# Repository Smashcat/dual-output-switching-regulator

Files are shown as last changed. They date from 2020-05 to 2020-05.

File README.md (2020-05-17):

# dual-output-switching-regulator
Small board with single 8-26v input and 5V@1.7A + 3.3V@500mA dual output via switching regulator

This board uses the cheap BD93291EFJ switching buck regulator which offers dual output, and is much more efficient than using linear regulators, while also allowing for higher input voltages than typical linear regulators; up to 26V. The board is very small - just 21mm x 30mm, so you can have 20 made at JLCPCB for under $1 :) Pin pitches are all quite large for surface mount, so a stencil isn't necessary to solder this board.

The pin headers are 2.54mm pitch, as the board is designed to be plugged into a breadboard as a convenient dual-rail power supply.

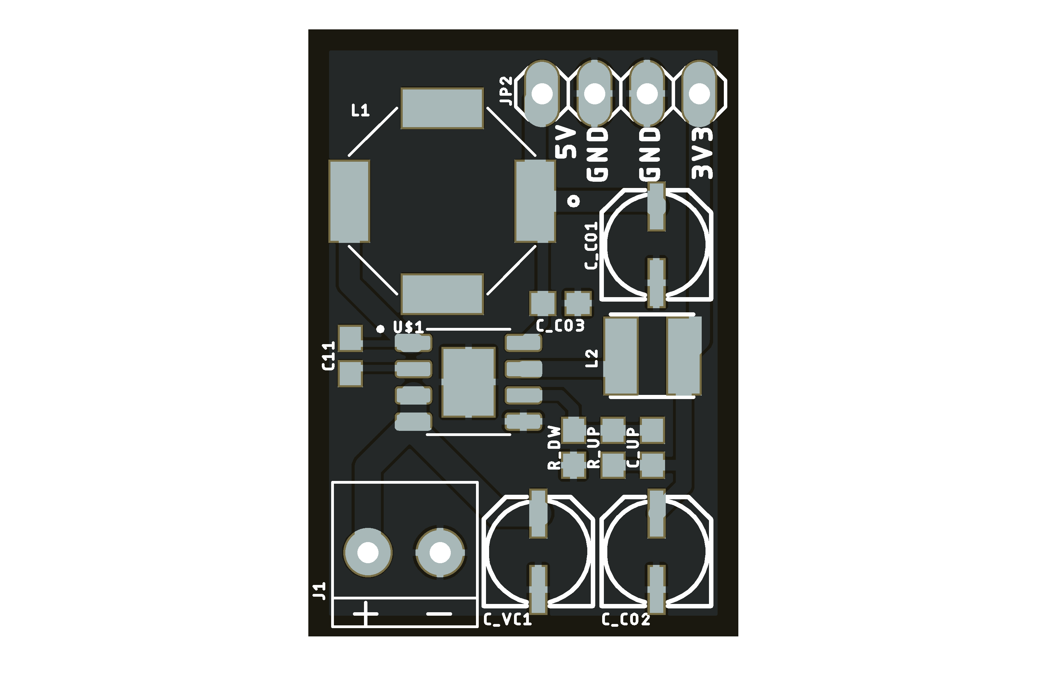
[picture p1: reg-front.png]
Front of PCB


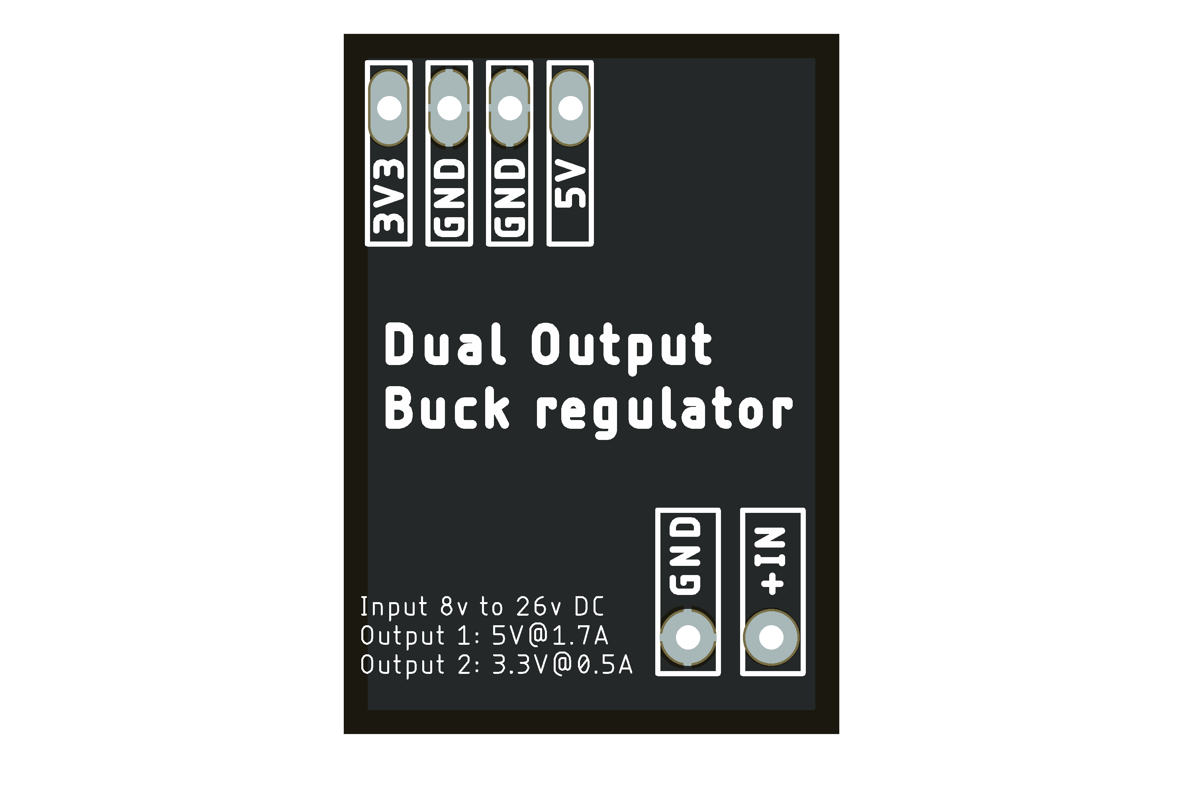
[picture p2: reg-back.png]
Back of PCB


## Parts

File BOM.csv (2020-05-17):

Part | Value | Device | Package | Description
C11 | 0.1uF | 0.1UF-0603-25V-(+80/-20%) | 0603 | 0.1µF ceramic capacitors
C_CO1 | 47uF | 47UF-POLAR-PANASONIC_C-35V-20% | PANASONIC_C | 47µF polarized capacitors
C_CO2 | 47uF | 47UF-POLAR-PANASONIC_C-35V-20% | PANASONIC_C | 47µF polarized capacitors
C_CO3 | 10uF | 10UF-0603-25V-(+80/-20%) | 0603 | 10µF ceramic capacitors
C_UP | 680pF | pF-0603-25V-(+80/-20%) | 0603 | 680pF ceramic capacitors
C_VC1 | 47uF | 22UF-POLAR-PANASONIC_C-35V-20% | PANASONIC_C | 47µF polarized capacitors
J1 | 1X2-3.5MM | 1X2-3.5MM | 1X2-3.5MM | 3.5mm Terminal block
JP2 | 3A | PINHD-1X4 | 1X04 | PIN HEADER
L1 | SRU1063-220Y | SRU1063-220Y | IND_SRU1063-220Y | Ind Power Shielded Wirewound 22uH 30% 100KHz 15Q-Factor Ferrite 3A T/R
L2 | SRN4018-2R2M | SRN4018-2R7M | INDP4040X180N | Inductor Power Semi-Shielded Wirewound 47uH 20% 100KHz Ferrite 600mA 780mOhm DCR 1515 T/R
R_DW | 5K1 | 5K1OHM-0603-1/10W-1% | 0603 | 5.1kΩ resistor
R_UP | 16K | 16KOHM-0603-1/10W-1% | 0603 | 16kΩ resistor
U$1 | BD93291EFJ | BD93291EFJ | SOIC127P600X100-9N

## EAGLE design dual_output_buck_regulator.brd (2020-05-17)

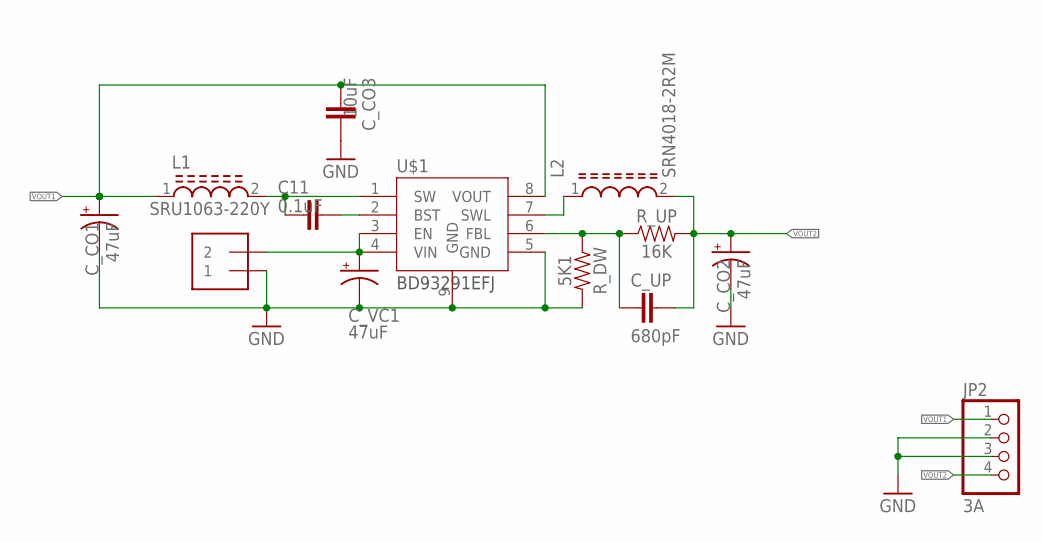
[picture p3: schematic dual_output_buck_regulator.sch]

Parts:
C11: 0.1uF; 0603
C_CO1, C_CO2: 47uF; PANASONIC_C
C_CO3: 10uF; 0603
C_UP: 680pF; 0603
C_VC1: 47uF; PANASONIC_C
J1: 1X2-3.5MM
JP2: 3A; 1X04
L1: SRU1063-220Y; IND_SRU1063-220Y
L2: SRN4018-2R2M; INDP4040X180N
R_DW: 5K1; 0603
R_UP: 16K; 0603
U$1: BD93291EFJ; SOIC127P600X100-9N

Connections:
GND: C_CO1.-, C_CO2.-, C_CO3.1, C_VC1.-, J1.1, JP2.2, JP2.3, R_DW.2, U$1.5 (GND), U$1.9 (GND)
unnamed: C_VC1.+, J1.2, U$1.3 (EN), U$1.4 (VIN)
unnamed: C11.1, U$1.2 (BST)
unnamed: C11.2, L1.2, U$1.1 (SW)
unnamed: C_UP.2, R_DW.1, R_UP.1, U$1.6 (FBL)
unnamed: L2.1, U$1.7 (SWL)
VOUT1: C_CO1.+, C_CO3.2, JP2.1, L1.1, U$1.8 (VOUT)
VOUT2: C_CO2.+, C_UP.1, JP2.4, L2.2, R_UP.2

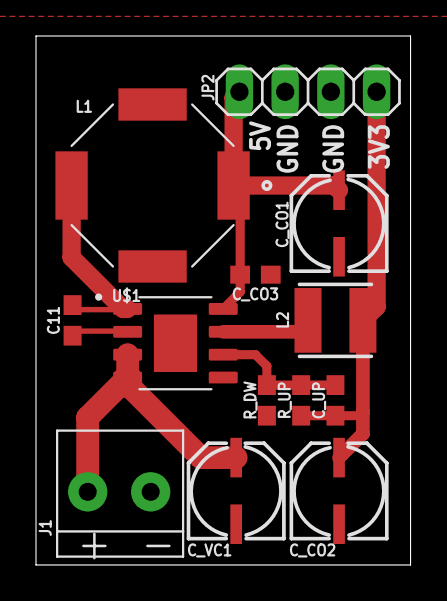
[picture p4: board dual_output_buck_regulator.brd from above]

Board: 2 copper layers, 20.8 x 29.4 mm, 13 parts (0 on the bottom side), 8 nets.

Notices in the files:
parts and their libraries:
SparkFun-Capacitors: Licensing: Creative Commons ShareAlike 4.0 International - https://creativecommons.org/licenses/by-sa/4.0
